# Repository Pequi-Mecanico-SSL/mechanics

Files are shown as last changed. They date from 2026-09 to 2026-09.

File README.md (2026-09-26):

# Pequi Mecânico SSL — Mechanics

Modelos de componentes e desenhos dimensionais para integração mecânica do robô SSL-EL. Seleção revisada em 26/09/2026 a partir dos nove arquivos iniciais fornecidos pela equipe, com a conversão adicional da placa de chute ZJUNlict Booster Board.

## Componentes para a montagem

Importar os modelos de `components/` no CAD do chassi. As quantidades indicadas são por robô; os arquivos não constituem uma montagem completa nem comprovam encaixes e folgas.

| Modelo | Qtd. | Utilização e conferência necessária |
| --- | ---: | --- |
| [Raspberry Pi 4 Model B](components/raspberry-pi-4-model-b.step) | 1 | Computador embarcado: suporte, acesso aos conectores e espaço para o HAT. [Desenho dimensional](references/raspberry-pi-4-model-b-dimensions.pdf). |
| [ST B-G431B-ESC1](components/st-b-g431b-esc1.step) | 4 | Controlador de cada motor: suporte, ventilação e cabos. Conferir se a placa destacável ST-LINK/BEC permanece no conjunto real. |
| [Nanotec DF45L024048-A](components/nanotec-df45l024048-a.step) | 4 | Motor de cada roda: fixação, posição e acoplamento ao cubo. |
| [GTF omniwheel 50 mm v4](components/gtf-omniwheel-50mm-v4.step) | 4 | Referência de roda omnidirecional: interferências, cubo e folga dos roletes. O projeto documenta rodas de 50 mm, mas a marca/revisão deste modelo precisa ser conferida na peça real. |
| [Pololu MinIMU-9 v5](components/pololu-minimu-9-v5.step) | 1 | Suporte da IMU: orientação dos eixos e acesso à fiação I2C. |
| [Waveshare RS485 CAN HAT](components/waveshare-rs485-can-hat.step) | 1 | Montagem sobre a Raspberry Pi: espaçadores, altura e saída dos cabos CAN. Conferir revisão da placa. |

As funções foram confrontadas com o TDP 2026 fornecido localmente e os repositórios [motor-controller](https://github.com/Pequi-Mecanico-SSL/motor-controller) e [pequi_ssl_el](https://github.com/Pequi-Mecanico-SSL/pequi_ssl_el). O [código de cinemática](https://github.com/Pequi-Mecanico-SSL/pequi_ssl_el/blob/3afe7e71667017f5217aa777948763932293336f/src/robot_control/robot_control/kinematics.py) usa raio efetivo de roda de 24,5 mm; não alterar essa calibração apenas pelo nome nominal de 50 mm do modelo.

## Placa de chute

A [referência da ZJUNlict Booster Board](references/kicker-board/README.md) inclui [STEP parcial](references/kicker-board/zjunlict-booster-board-partial.step), [STEP da placa nua](references/kicker-board/zjunlict-booster-board-bare.step), projeto editável no KiCad e prévia. Ambos os STEP passaram na validação geométrica do FreeCAD.

O contorno foi recuperado da camada mecânica e mede aproximadamente 147,71 × 129,09 mm. Apenas quatro dos 86 footprints têm modelos 3D associados. A espessura nominal importada de 0,41116 mm e os pequenos ajustes usados para fechar o contorno precisam ser conferidos na placa real; consultar as notas de conversão antes de dimensionar suportes ou folgas.

## Referências candidatas

Estes três arquivos são úteis para estudar fixações e passagem de cabos, mas sua adoção no robô ainda não está confirmada.

| Referência | Utilização e limite |
| --- | --- |
| [MR60PB-M-G-Y de 3 pinos](references/candidates/mr60pb-m-g-y-3pin.step) | Candidato para conexão das fases do motor. Conferir versão para placa, conector complementar e espaço para os cabos. |
| [XT90 macho](references/candidates/xt90-male.ipt) | Candidato para conexão de alimentação. Único modelo fornecido: Autodesk Inventor IPT; não há STEP e a geometria deste arquivo não foi validada. Para uso em outro CAD, exportar em software compatível. |
| [Solenoide SOLETEC 018](references/candidates/soletec-018-solenoid-dimensions.pdf) | Desenho mecânico na posição energizada: corpo de 33 × 22 × 15 mm e comprimento total de 59,5 ± 1,0 mm. Não informa tensão, força, resistência, curso completo ou ciclo de trabalho; não comprova equivalência ao solenoide customizado de 200 V citado no TDP. |

## Verificação

Os quatro ZIPs de origem passaram na verificação CRC de todas as entradas. Os sete STEP selecionados foram importados no FreeCAD 1.1.1 e passaram em `Shape.isValid()`, com geometria não vazia. Os dois PDFs foram renderizados e inspecionados. O IPT teve integridade da entrada ZIP conferida, mas não foi aberto no Inventor.

| Modelo STEP | Sólidos | Envelope X × Y × Z (mm) |
| --- | ---: | --- |
| Raspberry Pi 4B | 109 | 88,990 × 19,900 × 58,400 |
| ST B-G431B-ESC1 | 749 | 31,000 × 42,050 × 16,485 |
| Nanotec DF45L024048-A | 34 | 45,022 × 63,011 × 47,600 |
| GTF omniwheel 50 mm v4 | 89 | 48,459 × 49,200 × 12,601 |
| Pololu MinIMU-9 v5 | 1 | 20,320 × 12,700 × 2,216 |
| Waveshare RS485 CAN HAT | 95 | 65,022 × 30,022 × 18,500 |
| MR60PB-M-G-Y | 1 | 9,100 × 20,300 × 17,300 |

Os envelopes seguem a orientação original de cada modelo e incluem os detalhes modelados. Não equivalem necessariamente às dimensões nominais da placa. A validação geométrica não comprova correspondência com a peça real, montagem sem interferências ou desempenho elétrico.

## Seleção e nomes

Os modelos dos nove arquivos iniciais foram extraídos ou copiados sem alterar seu conteúdo; somente os nomes externos foram padronizados. A placa de chute foi convertida de Altium para KiCad/STEP, com os ajustes descritos em sua documentação. Os originais permanecem fora do repositório.

| Origem fornecida | Arquivo(s) aproveitado(s) |
| --- | --- |
| `raspberry-pi-4-model-b-1.snapshot.3.zip` | `Raspberry Pi 4 Model B.STEP` → `components/raspberry-pi-4-model-b.step`; `Raspberry Pi 4 Model B Dimensions.pdf` → `references/raspberry-pi-4-model-b-dimensions.pdf` |
| `B-G431B-ESC1.step` | `components/st-b-g431b-esc1.step` |
| `GTF Robots 50mm Wheel v4.step` | `components/gtf-omniwheel-50mm-v4.step` |
| `DF45L024048-A(1).stp` | `components/nanotec-df45l024048-a.step` |
| `solenoide 557 018.pdf` | `references/candidates/soletec-018-solenoid-dimensions.pdf`; modelo 018 identificado no desenho |
| `mr60pb-m-g-y-1.snapshot.1.zip` | `mr60pb-mgy_3pin.stp` → `references/candidates/mr60pb-m-g-y-3pin.step` |
| `xt90-male-plug-1.snapshot.2.zip` | `XT90 Male.ipt` → `references/candidates/xt90-male.ipt` |
| `minimu-9-v5-gyro-accelerometer-and-compass-lsm6ds33-and-lis3mdl-carrier.step` | `components/pololu-minimu-9-v5.step` |
| `RS485_CAN_HAT_3D_Drawing.zip` | `RS485_CAN_HAT_3D_Drawing/RS485_CAN_HAT.stp` → `components/waveshare-rs485-can-hat.step` |

Foram omitidos os ZIPs completos, imagens de apresentação, a montagem/peças SolidWorks e Parasolid da Raspberry Pi e os auxiliares `t19-3.stp`/`t19-3.prt.19` do HAT. Os STEP principais já permitem o estudo de posicionamento; os formatos omitidos permanecem nos downloads originais caso seja necessária edição nativa detalhada.

Para conferir a integridade dos arquivos selecionados, incluindo os modelos e o projeto da placa de chute, executar na raiz do repositório:

```sh
sha256sum -c SHA256SUMS
```

Os arquivos de terceiros foram fornecidos pela equipe sem URLs de origem ou licenças anexas identificadas. Nenhuma nova licença é atribuída a esses modelos.

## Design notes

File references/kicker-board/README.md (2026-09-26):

# Placa de chute — ZJUNlict Booster Board

Conversão do arquivo `Booster_Board-master.zip` fornecido pela equipe em 26/09/2026. Projeto original em Altium Designer, importado no KiCad 9.0.7 e exportado para STEP. Este é um modelo de referência mecânica **parcial**, não uma montagem completa nem um projeto de fabricação revisado.

## Arquivos

- [Modelo STEP parcial](zjunlict-booster-board-partial.step): placa e os quatro componentes que tinham modelos 3D incorporados e associados a footprints no projeto.
- [STEP da placa nua](zjunlict-booster-board-bare.step): substrato, contorno e furações exportadas.
- [Layout editável no KiCad](zjunlict-booster-board.kicad_pcb), com os modelos incorporados, e [configurações do projeto](zjunlict-booster-board.kicad_pro).
- [Prévia do KiCad](preview.png): mostra também cobre e serigrafia; os STEP finais omitem essas camadas visuais.

## O que foi recuperado

Foram importados 86 footprints. Quatro têm modelos 3D: `L2` (MSS1210-683MED), `C19` e `C20` (T523H477M016APE0707280) e `Designator1` (modelo denominado `power connector.STEP`). Os outros 82 footprints não têm modelos 3D associados na conversão. Sua presença no layout ou na serigrafia não significa que seu volume esteja representado no STEP.

Logo, a altura total calculada do STEP parcial **não é a altura máxima da placa montada**. Módulos MP1584, conectores, chave, capacitores e outros componentes visíveis nas fotos precisam de modelos e posições conferidos antes de validar interferências com o robô.

## Contorno mecânico

A forma de placa armazenada no campo de board shape do Altium é um polígono quase retangular, diferente do contorno recortado da placa fotografada. O desenho da camada `Mechanical 1` corresponde visualmente à foto da versão 2019 e foi usado para gerar o `Edge.Cuts` deste derivado.

O desenho mecânico original continha pequenos desencontros entre segmentos. Na cópia de trabalho foram removidos um segmento duplicado e um segmento de comprimento praticamente zero, unidos dois segmentos verticais sobrepostos, e ajustadas 26 extremidades de retas para fechar o contorno. O deslocamento máximo foi **0,311254 mm**, dentro da tolerância de agrupamento de 0,35 mm. Os arcos originais foram preservados. O contorno resultante contém 28 retas, 10 arcos e dois círculos de furos. O desenho `Mechanical 1` permanece no arquivo para comparação.

Isso é uma reconstrução do desenho fornecido, não uma medição da peça fabricada. Conferir contorno, posições dos furos e pequenas tolerâncias com a placa real antes de fabricar suportes. O arquivo original não foi alterado.

## Dimensões e validação

Ambos os STEP finais foram reabertos no FreeCAD 1.1.1 e passaram em `Shape.isValid()`, inclusive todos os sólidos individualmente.

| Arquivo | Sólidos | Envelope X × Y × Z (mm) |
| --- | ---: | --- |
| Placa nua | 1 | 147,70795 × 129,08513 × 0,32116 |
| Montagem parcial | 11 | 147,70795 × 129,08513 × 19,51116 |

O KiCad importou **0,41116 mm de espessura nominal de placa**. O STEP sem cobre exporta um substrato de **0,32116 mm**; a diferença vem das camadas externas omitidas pelo exportador. A espessura é incomum para este tipo de placa e precisa ser confirmada fisicamente. Ela foi preservada, sem assumir 1,6 mm. Os dados de empilhamento do Altium também contêm valores muito finos (núcleo de 12,6 mil e cobre de 1,4 mil por face).

O importador emitiu avisos `Unexpected Layer ID`; o resultado foi inspecionado para referência mecânica, não validado eletricamente ou para fabricação. A primeira exportação com cobre/serigrafia não passou na validação geométrica e não está incluída nesta pasta. Os STEP finais foram exportados sem esses elementos e passaram na validação.

## Reprodução da exportação

Na pasta deste projeto, com KiCad 9:

```sh
kicad-cli pcb export step -o booster-partial.step zjunlict-booster-board.kicad_pcb
kicad-cli pcb export step --board-only -o booster-bare.step zjunlict-booster-board.kicad_pcb
```

Na instalação Snap, substituir `kicad-cli` por `kicad.kicad-cli`. Para inspecionar, abrir o `.kicad_pcb` no PCB Editor e usar o visualizador 3D (`Alt+3`).

## Procedência

- Projeto: [ZJUNlict/Booster_Board](https://github.com/ZJUNlict/Booster_Board), versão 2019 conforme README do arquivo fornecido. As capturas 3D de 2018 também estão no ZIP e não representam a revisão 2019 completa.
- Revisão registrada no comentário do ZIP: `d5fa47cd16713b73b239209bb32c646890c3a289`.
- SHA-256 do ZIP fornecido: `a4ba0fe5ceaa91873fa818f8d310cfb279b4cea9df956c15c5282f4afe0ac4c7`.
- As fontes Altium estão no ZIP original; esta pasta contém o derivado KiCad e as exportações mecânicas. O arquivo `.kicad_pcb` incorpora os modelos 3D utilizados na exportação.

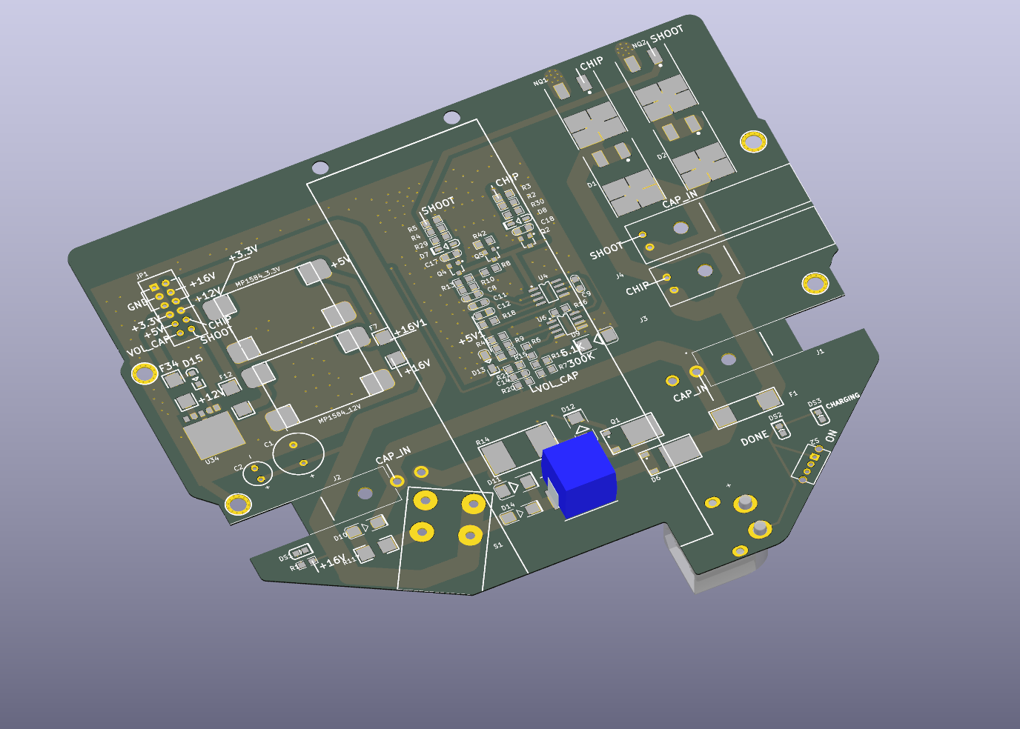
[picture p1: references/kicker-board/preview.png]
Prévia da conversão parcial


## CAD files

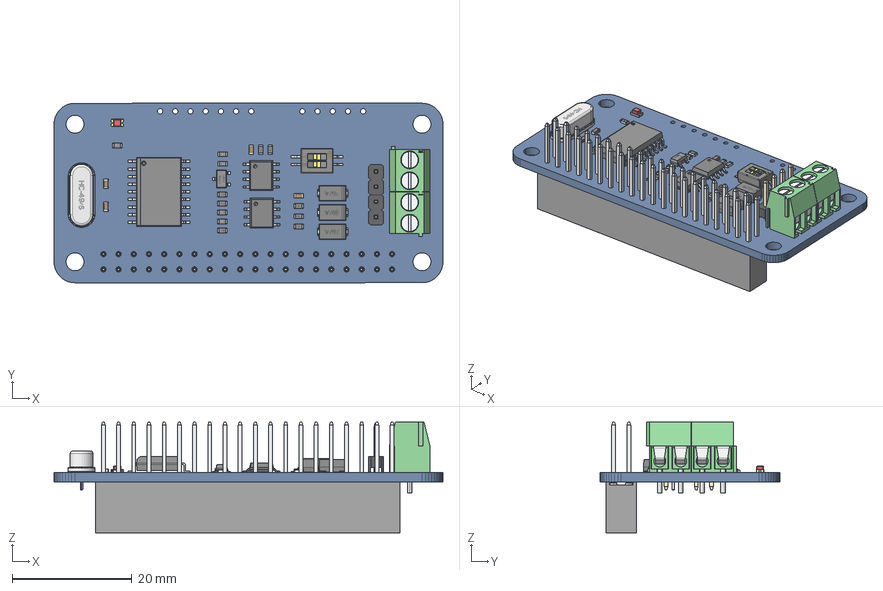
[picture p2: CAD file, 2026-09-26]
components/waveshare-rs485-can-hat.step
65.0 x 30.0 x 18.5 mm
BOARD_1
SMA-5401_AF0 x 3
CAPC1608_0603_ x 4
_2_1_2_3_4_AF0_1 x 13
_7_1_2_AF0_1 x 13
USER_LIBRARY-SOP-8 x 2
USER_LIBRARY-SOIC18-300
HC-49S_N
HEADER_2_54X2 x 2
CSW1_27-SMD-2P-913
SOT-23
USER_LIBRARY-LED_0805
USER_LIBRARY-DG350-3_5-02P_1 x 2
USER_LIBRARY-DG350-3_5-02P_2 x 2
USER_LIBRARY-DG350-3_5-02P_3 x 2
USER_LIBRARY-DG350-3_5-02P_4 x 2
USER_LIBRARY-DG350-3_5-02P_5 x 2
FEMALE-2_54MM-H8_5-2X20P-V

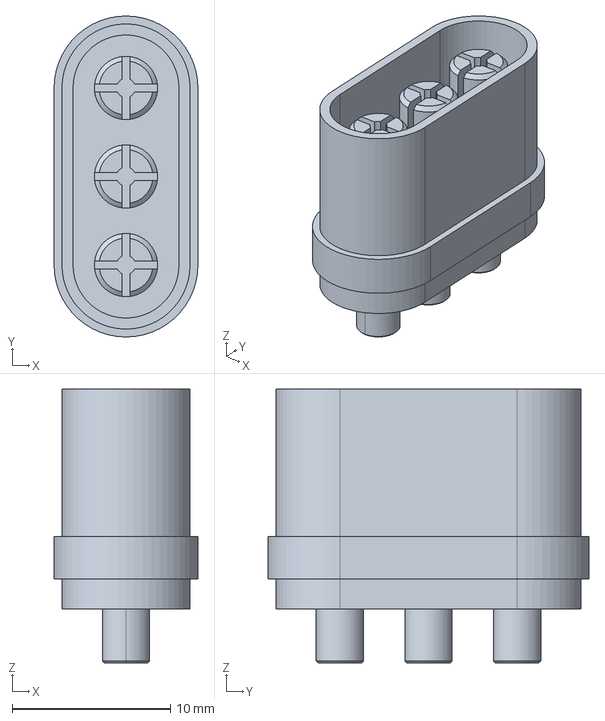
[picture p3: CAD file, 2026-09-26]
references/candidates/mr60pb-m-g-y-3pin.step
9.10 x 20.3 x 17.3 mm

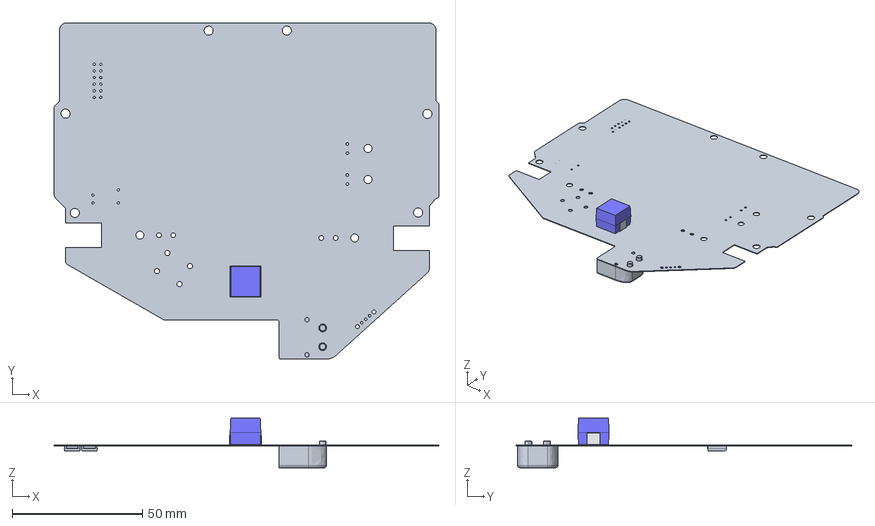
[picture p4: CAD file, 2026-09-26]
references/kicker-board/zjunlict-booster-board-partial.step
147.7 x 129.1 x 19.1 mm
FilletPin1 x 3
FilletPin2 x 3
kicad_embedded_4AC53AD4C5CF69C6F659C2ED0629CD60
zjunlict-booster-board-mechanical_PCB

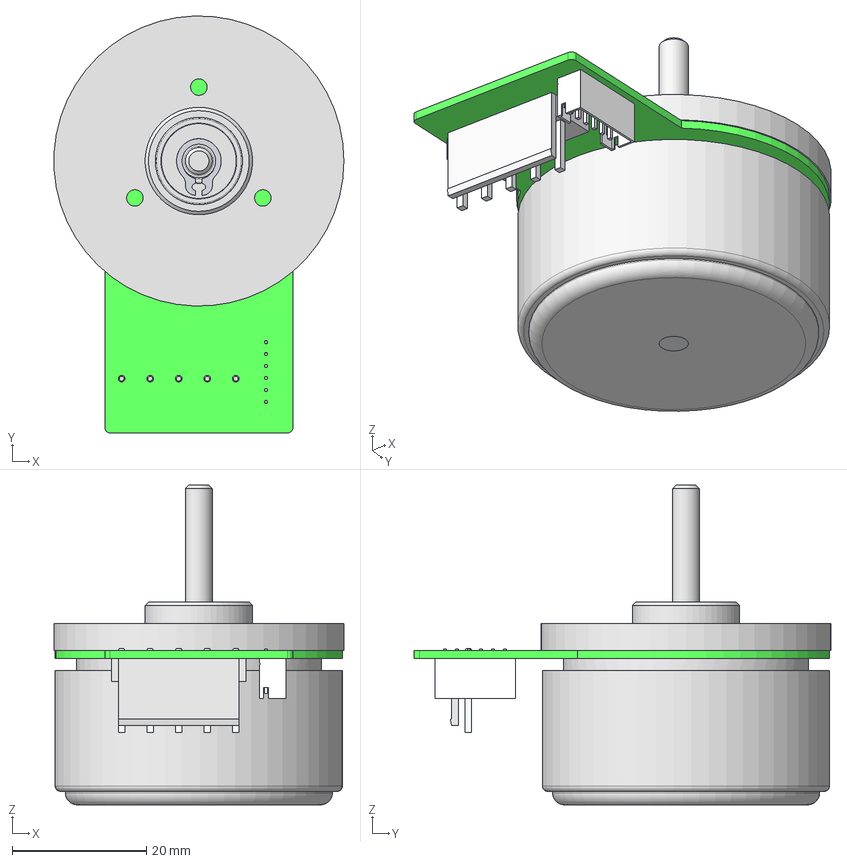
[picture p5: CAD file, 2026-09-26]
components/nanotec-df45l024048-a.step
43.2 x 62.1 x 47.6 mm
Frontcap-DF45L
PCB-DF45-A
Glocke-DF45L
Welle-DF45L
Innenteil-DF45L
_R-1350ZZ_ir x 2
_R-1350ZZ_cage x 2
_R-1350ZZ_ball x 16
_R-1350ZZ_or x 2
_R-1350ZZ_shield x 4
DIN 471 <= 9mm 5 x 0,6
Connector 1
Connector 2

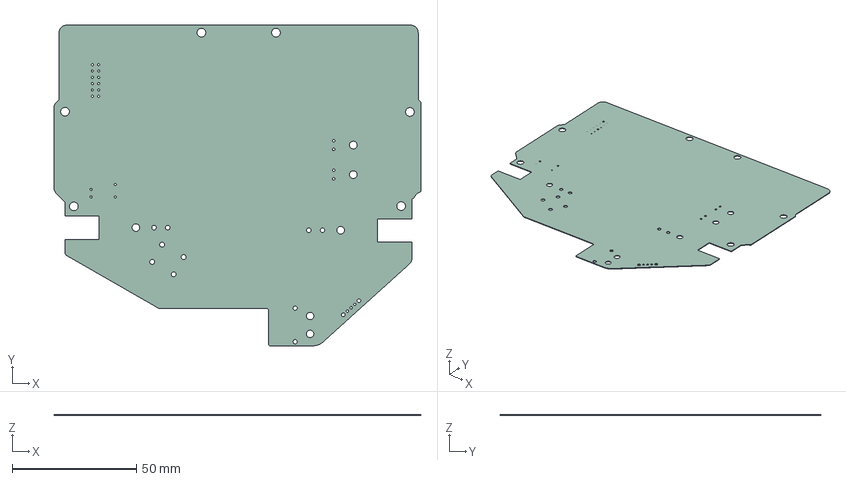
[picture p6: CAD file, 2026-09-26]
references/kicker-board/zjunlict-booster-board-bare.step
147.7 x 129.1 x 0.321 mm

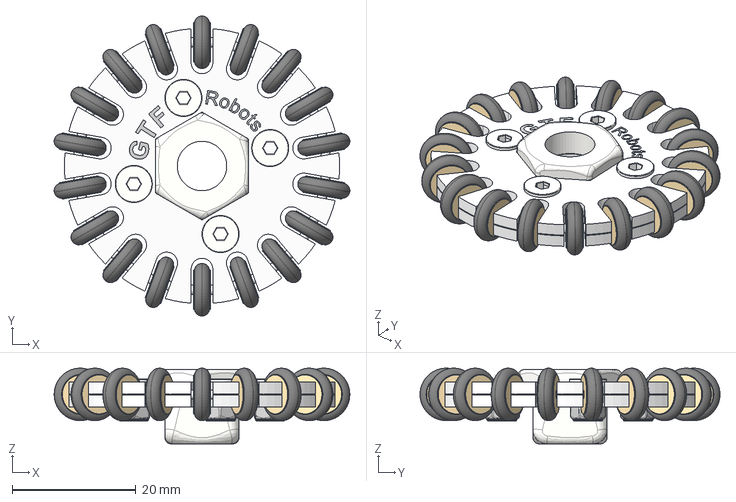
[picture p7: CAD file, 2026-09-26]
components/gtf-omniwheel-50mm-v4.step
47.8 x 48.5 x 12.3 mm

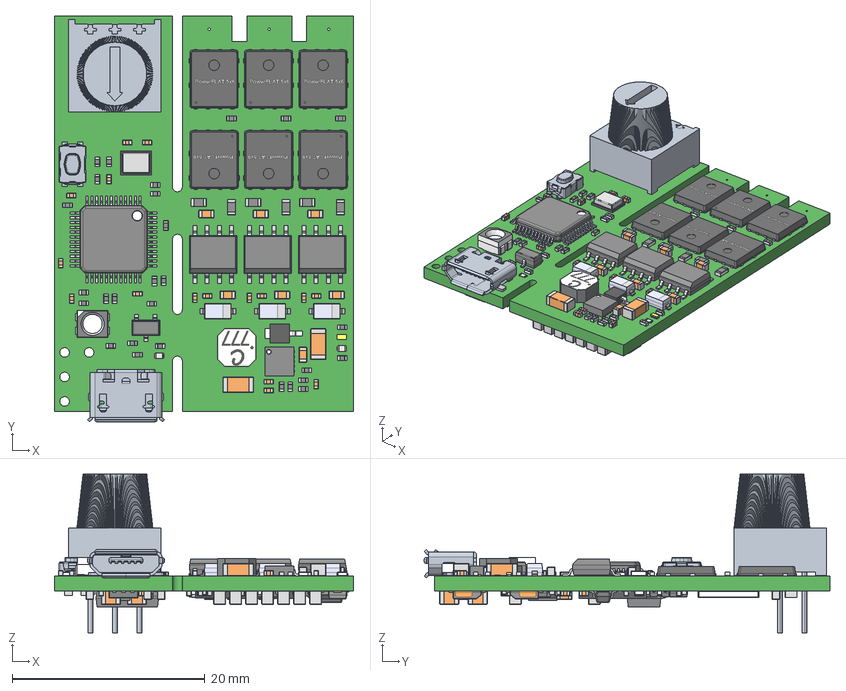
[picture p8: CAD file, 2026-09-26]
components/st-b-g431b-esc1.step
31.0 x 42.0 x 16.5 mm
CAPC2012X140 x 16
cover
housing
base x 2
SON50P300X300X100-11
PowerFLAT 5x6 x 6
SON7P95_300X300X100L40X34T23-1
RESC1608X50 x 11
INDC1005X55
3386-T
SON65P300X300X100-9
KMR211GLFS
SOT95P255X140-3
QFP50P900X900X145-48
XTALDFN320X250X100-2
SOT-223
QFN6 x 2
SON40P120X100X55-6
SOT238
0435.250KRS
User Library-LED_1006_G_Cut006 x 2
User Library-LED_1006_G_Cut005 x 2
User Library-LED_1006_G_Cut005_(Mirror_#1) x 2
User Library-LED_1006_G_Pad001 x 2
C281-1
C281-2
C281-3
C281-4
C281-5
C281-6
C281-7
SOD123 x 3
CAPC1608X90 x 14
SODFL1608X65 x 10
LPS4018
DO-216AA
CAPC3216X127 x 2
CSTCE
QFN48 7x7
CAPC1005X55 x 38
RESC2012X70 x 3
RESC1005 x 62
DO216-AA-FLAT x 2
SOIC127P600X175 x 3
RESC6330 x 3

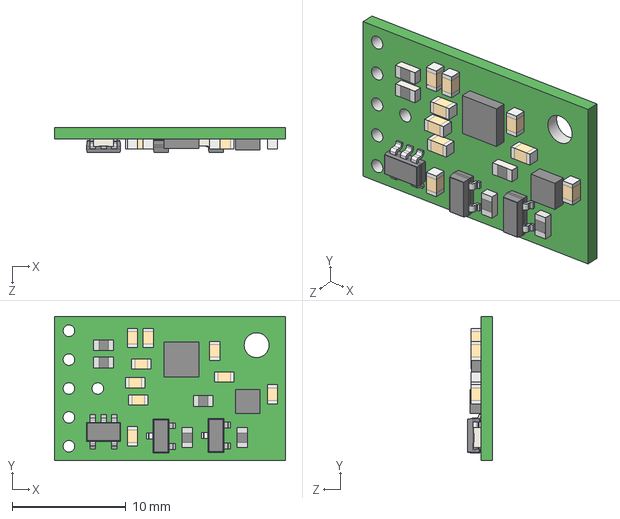
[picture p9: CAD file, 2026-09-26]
components/pololu-minimu-9-v5.step
20.3 x 12.7 x 2.22 mm

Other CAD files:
references/candidates/xt90-male.ipt

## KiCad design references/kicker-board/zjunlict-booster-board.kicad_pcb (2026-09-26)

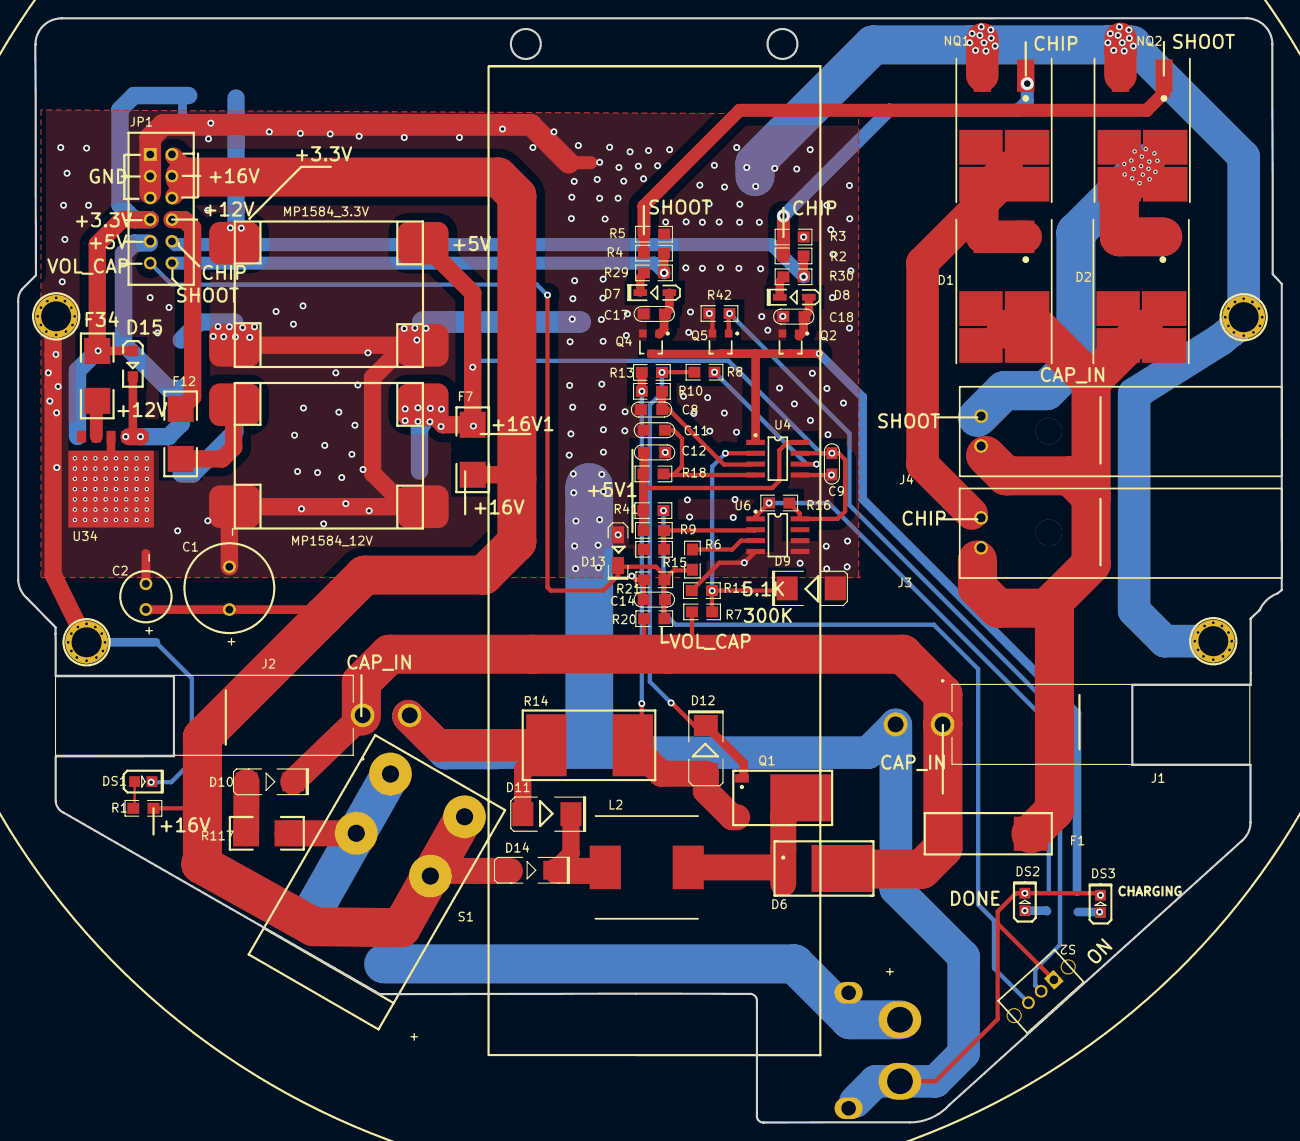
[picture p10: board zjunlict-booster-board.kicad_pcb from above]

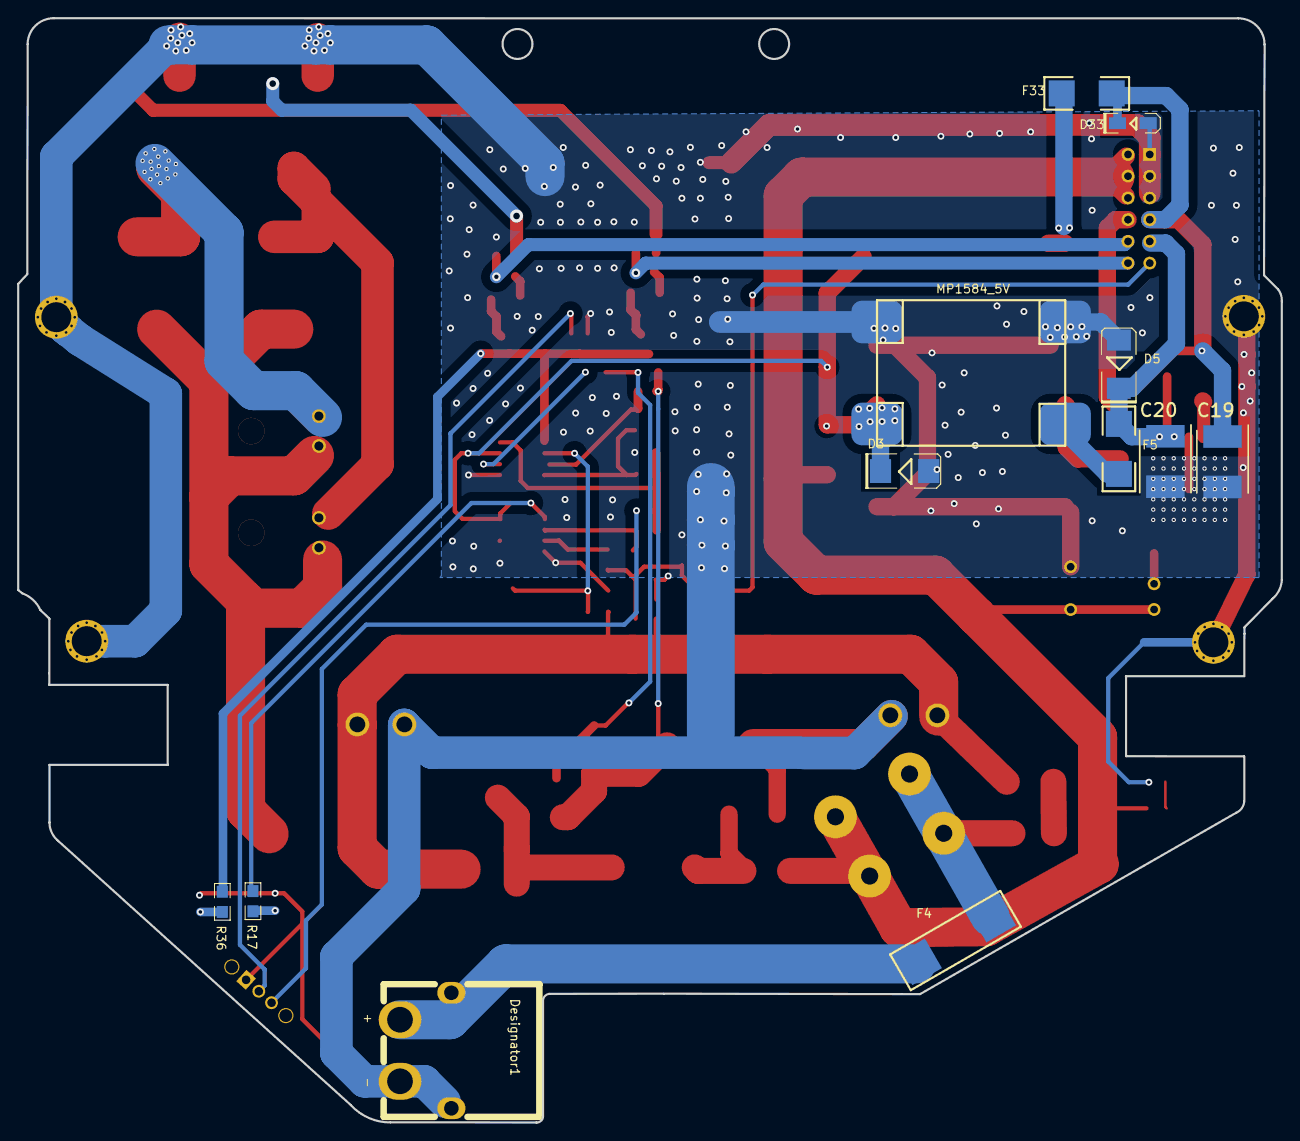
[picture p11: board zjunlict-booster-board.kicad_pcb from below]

Board: 2 copper layers, 147.7 x 129.1 mm, 86 parts (12 on the bottom side), 44 nets.

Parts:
C1: 330uF; 470uF
C2: 100uf; 100uF
C8: 470p; 0805C
C9, C14: 0.1uF; 0805C
C11: 2.2nf; 0805C
C12: 0.1uf; 0805C
C17, C18: 0.1uF; 0805c
C19, C20: CAP470; CAPPM7360X200N
D1, D2: MBRB40250CT; D2PAK
D3, D11, D12: SMBJ18A; SMBJ6.5
D5, D9: SMBJ6.5CA; SMBJ6.5
D6: MURD620; DPAK
D7, D8: B5819; sod-123
D10, D14: M7; SMA
D13, D33: SMF3.3; SMF33
D15: MBR120VLSFT1G SOD123; sod123
DS1, DS2: LED2; 0805A
DS3: LED3; 0805A
Designator1: Comment; XT60PW
F1, F4: 20A
F5, F7, F12, F33, F34: 3A; 2512r
J1, J2: 0768250002; 0768250002_version2
J3, J4: 172310-1102; 172310-1102_VERSION2
JP1: Header 4X2; 2*6_2.5mm
L2: 68uH; INDPM120120X1020N
MP1584_3.3V, MP1584_5V, MP1584_12V: MP1584; 1584
NQ1, NQ2: IPB64N25S3-20; D2PAK
P7, P8, P9, P10: BNC; hole
Q1: IRFR12N25D; DPAK
Q2: 9014; SOT23A
Q4: 9014; sot23a
Q5: 9014; SOT23a
R1, R3, R5, R13, R21: 10k; 0805R
R2, R4: 100; 0805r
R6, R9: 10K; 0805R
R7: 390K; 0805R
R8: 10; 0805R
R10, R15: 1k; 0805R
R11: 3.3K; 0805R
R14: 0.2; 0.2_4527R
R16, R17: 4.7k; 0805R
R18: 27k; 0805R
R20: 1m; 0805R
R29, R30: 10K; 0805r
R36: 4.7K; 0805r
R41, R42: 10k; 0805r
R117: 20; 20_2512r
S1: power; Rocker_Switch
S2: SW-SPDT; SMALL_switch
U4: UC3843P; SO-G8
U6: LM393; LM393_SO-G8
U34: BA33DD0WHFP; HRP5_16TO5

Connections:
+3.3V: C19.1, D15.1, D33.2, F33.1, F34.2, JP1.7
+5V: C20.1, D5.2, D15.2, F5.1, JP1.9, U34.1, U34.2
+5V1: C12.1, R9.2, R18.2, R41.2, U4.8
+12V: F12.1, JP1.8
+16V: C1.1, C2.1, D14.1, F7.2, JP1.2, JP1.4, JP1.6, R1.2, S1.1, S1.3
+16V1: C9.2, D3.2, F7.1, MP1584_3.3V.2, MP1584_5V.2, MP1584_12V.2, R16.2, U4.7, U6.8
BATTERY: Designator1.2, F4.2
BATTERY_IN: F4.1, R117.2, S1.2, S1.4
CHIP: JP1.10, R2.1, R30.1
CMPEN: Q2.3, Q4.3, Q5.3, R36.2, U4.1
COIL_CHIP: D1.1, D1.3, J3.2, NQ1.2
COIL_SHOOT: D2.1, D2.3, J4.2, NQ2.2
CURRENT: C8.1, R10.2, U4.3
GND: C1.2, C2.2, C8.2, C9.1, C11.2, C12.2, C14.1, C17.1, C18.1, C19.2, C20.2, D3.1, D5.1, D9.1, D11.1, D13.1, D33.1, DS1.2, DS2.2, DS3.2, Designator1.1, J1.2, J2.2, JP1.1, JP1.3, JP1.5, MP1584_3.3V.1, MP1584_3.3V.4, MP1584_5V.1, MP1584_5V.4, MP1584_12V.1, MP1584_12V.4, NQ1.3, NQ2.3, P7.1, P8.1, P9.1, P10.1, Q2.2, Q4.2, Q5.2, R3.1, R5.1, R11.1, R14.1, R15.2, R21.1, R42.2, S2.1, U4.5, U6.4, U6.5, U6.6, U34.3, U34.FIN
NetC11_1: C11.1, R18.1, U4.4
NetC17_2: C17.2, D7.1, Q4.1
NetC18_2: C18.2, D8.1, Q2.1
NetD6_1: D6.1, D6.3, L2.2, Q1.2
NetD7_2: D7.2, R29.1
NetD8_2: D8.2, R30.2
NetD10_1: D10.1, R117.1
NetD11_2: D11.2, D14.2, L2.1
NetD12_1: D12.1, Q1.3, R10.1, R13.1, R14.2
NetD12_2: D12.2, Q1.1, R8.2, R13.2
NetDS1_1: DS1.1, R1.1
NetDS2_1: DS2.1, R17.1
NetDS3_1: DS3.1, R36.1
NetF5_2: F5.2, MP1584_5V.3
NetF12_2: F12.2, MP1584_12V.3
NetF33_2: F33.2, MP1584_3.3V.3
NetF34_1: F34.1, U34.4
NetNQ1_1: NQ1.1, R2.2, R3.2
NetNQ2_1: NQ2.1, R4.2, R5.2
NetQ5_1: Q5.1, R42.1, S2.2
NetR6_1: R6.1, U6.3
NetR9_1: R9.1, R15.1, U6.2
NetR16_1: R16.1, R17.2, U6.1
NetR41_1: R41.1, S2.3
PWMOUT: R8.1, U4.6
SHOOT: JP1.12, R4.1, R29.2
VBACK: D9.2, R7.1, R11.2, U4.2
VCAP_IN: D6.2, D10.2, F1.1, J1.1, J2.1, R7.2, R20.2
VCAP_OUT: D1.2, D2.2, F1.2, J3.1, J4.1
VOLTAGE_CAP: C14.2, D13.2, JP1.11, R6.2, R20.1, R21.2

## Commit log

2026-09-26 Add reviewed mechanical component models and dimensional references
    [gtf-omniwheel-50mm-v4.step, mr60pb-m-g-y-3pin.step, nanotec-df45l024048-a.step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]
2026-09-26 Add kicker board STEP models and editable KiCad reference
    [zjunlict-booster-board-bare.step, zjunlict-booster-board-partial.step, zjunlict-booster-board.kicad_pcb]
